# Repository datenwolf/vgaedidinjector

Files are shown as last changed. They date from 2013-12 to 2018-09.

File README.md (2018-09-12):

# VGA EDID Injector

Captures EDID information from a display and presents it to a computer. Useful in situations where the DDC lines are not connected (like the CCH).
* sources	https://github.com/datenwolf/vgaedidinjector
* project at C3VOC wiki	https://c3voc.de/wiki/hardware:vga_edid_injector

The VGA EDID Injector is a tool that aims to make the use of presentation infrastructure less painful. In many conference venues the presentation displays (video projectors aka "beamers") are connected using old fashioned analogue connections using high quality coax cable. While this method offers a very good image quality it suffers from the lack of a DDC channel for transmission of EDID data.

Modern operating systems however depend on the EDID information for mode setting. Even worse on some operating systems it is very hard or even impossible to override the settings obtained from the EDID data. Those operating systems also usually fall back to a set of safe display resolutions and timings if no EDID data could be retrieved via DDC. Unfortunately those safe timings usually don't match the physical resolution of the display device, resulting in bad looking scaling and/or worse distortion of the aspect ratio (e.g. fall back resolution 1024×768 (4:3 aspect), display device physical resolution 1280×720 (16:9) resulting in squashed image, i.e. pancake heads, and so on…).

The VGA EDID Injector provides relief for this kind of situation: It allows to take a snapshot of a display's EDID information and "carry" it to the computer in need.

## Hardware
The VGA EDID Injector has 3 connectors (see image):

* D-Sub 15 H (VGA) female, left side of the board – connect to display device
* D-Sub 15 H (VGA) male, right side of the board – connect to computer
* Micro-USB, lower side of the board – for providing auxiliary power (+5V); upcoming firmware revisions will provide a command line interface

## Usage
### Snapshoting Display EDID information

To snapshot the EDID connection you have to insert the injector in reverse direction. This typically requires you to use the VGA gender changer and the VGA cable.

* Connect the display to the left side, female VGA connector. 
* Plug the right side, male VGA connector into a computer

Using the display control tools refresh/identify connected displays. Repeat this until the attached display is recognized.
The VGA EDID Injector can now be spliced into the computer side of a video signal only (i.e. no DDC signals) connection.

### Replaying snapshoted EDID information
Insert the VGA EDID Injector into the video signal connection close to the computer.

**Important Notice:** There must be no DDC signals present on the display side of the connection. Otherwise the VGA EDID Injector will try to attempt to snapshot the information found there and, if successful, will overwrite the previously snapshoted EDID information.

In that case it is recommended to prepare a special VGA cable in which the signal carried over the pins 12 and 15 is severed (simply removing the pins from one of the connectors with some side cutters and/or pliers will do the trick).

### Micro-USB connector
An upcoming firmware release will provide a command line interface over USB CDC ACM serial device emulation. Until then the Micro-USB connector serves for supplying auxiliary power (+5V). Under normal circumstances the VGA connection will provide +5V, 50mA(max) over pin 9. However long cable lengths or a "weak" system's power supply (think laptops) may prevent the supply to meet the demands.

The circuitry of the VGA EDID Injector incorporates two rectifier diodes to prevent current to flow back into either the VGA port or the Micro-USB if both are connected at the same time, or should a computer get accidently connected on the display side. However those diodes create a 0.7V voltage drop.

Hence should the VGA EDID Injector seem to be nonoperational it is suggested to provide auxiliary power through the Micro-USB connector.

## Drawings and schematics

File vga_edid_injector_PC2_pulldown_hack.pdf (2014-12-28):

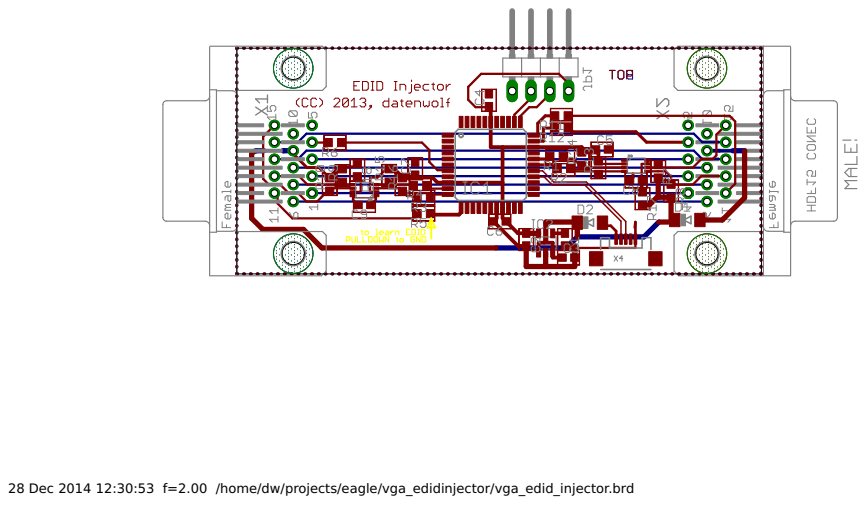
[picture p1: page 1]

28 Dec 2014 12:30:53 f=2.00 /home/dw/projects/eagle/vga_edidinjector/vga_edid_injector.brd

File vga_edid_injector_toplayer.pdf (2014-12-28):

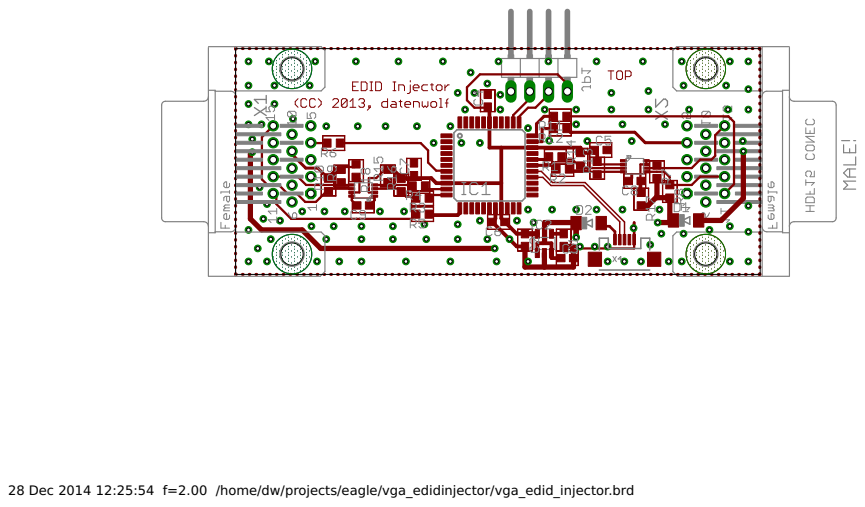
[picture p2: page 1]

28 Dec 2014 12:25:54 f=2.00 /home/dw/projects/eagle/vga_edidinjector/vga_edid_injector.brd

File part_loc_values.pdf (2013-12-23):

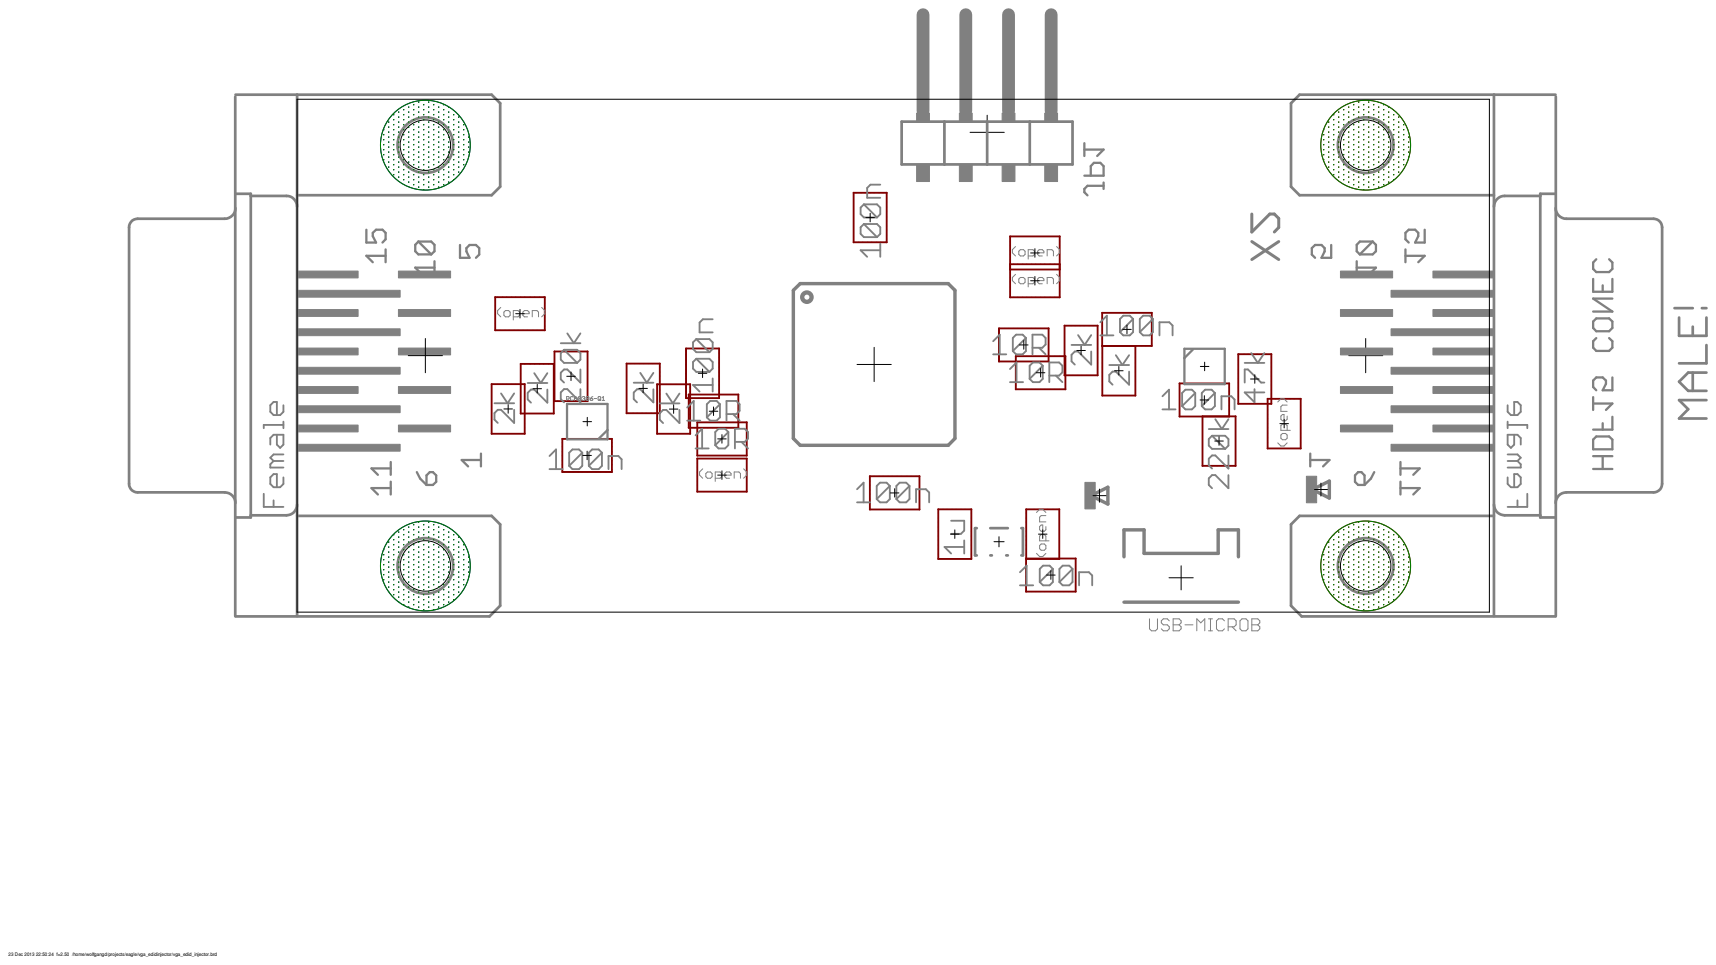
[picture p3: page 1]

23 Dec 2013 22:50:24 f=2.50 /home/wolfgangd/projects/eagle/vga_edidinjector/vga_edid_injector.brd

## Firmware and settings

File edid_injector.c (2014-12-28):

/* This file has been prepared for Doxygen automatic documentation generation.*/
/*! \file *********************************************************************
 *
 * \brief  EDID Injector firmware
 *
 * \author
 *      Wolfgang 'datenwolf' Draxinger
 *      Support email: projects+edid_injector@datenwolf.net
 *
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
 * 3. The name of ATMEL may not be used to endorse or promote products derived
 * from this software without specific prior written permission.
 *
 * THIS SOFTWARE IS PROVIDED BY ATMEL "AS IS" AND ANY EXPRESS OR IMPLIED
 * WARRANTIES, INCLUDING, BUT NOT LIMITED TO, THE IMPLIED WARRANTIES OF
 * MERCHANTABILITY AND FITNESS FOR A PARTICULAR PURPOSE ARE EXPRESSLY AND
 * SPECIFICALLY DISCLAIMED. IN NO EVENT SHALL ATMEL BE LIABLE FOR ANY DIRECT,
 * INDIRECT, INCIDENTAL, SPECIAL, EXEMPLARY, OR CONSEQUENTIAL DAMAGES
 * (INCLUDING, BUT NOT LIMITED TO, PROCUREMENT OF SUBSTITUTE GOODS OR SERVICES;
 * LOSS OF USE, DATA, OR PROFITS; OR BUSINESS INTERRUPTION) HOWEVER CAUSED AND
 * ON ANY THEORY OF LIABILITY, WHETHER IN CONTRACT, STRICT LIABILITY, OR TORT
 * (INCLUDING NEGLIGENCE OR OTHERWISE) ARISING IN ANY WAY OUT OF THE USE OF
 * THIS SOFTWARE, EVEN IF ADVISED OF THE POSSIBILITY OF SUCH DAMAGE.
 *****************************************************************************/
#include "avr_compiler.h"

#include <string.h>

#include "eeprom_driver.h"

#include "twi_master_driver.h"
#include "twi_slave_driver.h"

/*! BAUDRATE 100kHz and Baudrate Register Settings */
#define BAUDRATE	100000
#define TWI_BAUDSETTING TWI_BAUD(F_CPU, BAUDRATE)

#define EDID_SLAVE_ADDRESS 0x50

/* TWIC is on the display side */
TWI_t * const twiDisplay = &TWIC;
TWI_Master_t twimDisplay;    /*!< TWI master module. Used for talking with display */
/*! TWIC Master Interrupt vector. */
ISR(TWIC_TWIM_vect)
{
	TWI_MasterInterruptHandler(&twimDisplay);
}


/* TWIE is on the host side */
TWI_t * const twiHost = &TWIE;
TWI_Slave_t twisHost;      /*!< TWI slave module.  Used for talking with host */
/*! TWIC Slave Interrupt vector. */
ISR(TWIE_TWIS_vect)
{
	TWI_SlaveInterruptHandler(&twisHost);
}

#define EDID_BLOCK_LENGTH 128

static uint8_t edid_data[EDID_BLOCK_LENGTH];
static uint8_t edid_offset;
static uint8_t recvbuf[1];

void TWIC_SlaveProcessData(TWI_Slave_t * const twi)
{
	if( twi->bytesReceived ) {
		edid_offset = twi->recvData[0];
	}
	twi->sendData = edid_data + edid_offset;
	twi->bytesToSend = sizeof(edid_data) - edid_offset;
}

void edid_initHostTWI(void)
{
	/* Initialize TWI slave. */
	TWI_SlaveInitializeDriver(&twisHost,
		twiHost,
		TWIC_SlaveProcessData);

	TWI_SlaveInitializeModule(&twisHost,
		EDID_SLAVE_ADDRESS,
		TWI_SLAVE_INTLVL_HI_gc,
		recvbuf,
		sizeof(recvbuf) );
}

void edid_initDisplayTWI(void)
{
	/* Initialize TWI master. */
	twimDisplay.status = TWIM_STATUS_READY;
	TWI_MasterInit(&twimDisplay,
	               twiDisplay,
	               TWI_MASTER_INTLVL_LO_gc,
	               TWI_BAUDSETTING);

	/* Enable internal pull-up on PC0, PC1. */
	/* If you don't have external pullups enable this */
#if 0
	/* Configure several PINxCTRL registers at the same time */
	PORTCFG.MPCMASK = 0x03; 

	/* Enable pull-up to get a defined level on the switches */
	PORTC.PIN0CTRL = (PORTC.PIN0CTRL & ~PORT_OPC_gm) | PORT_OPC_PULLUP_gc;
#endif

}

uint8_t edid_checkData(uint8_t const *ediddata)
{
	uint8_t checksum = 0;
	for(uint8_t i = 0; i < EDID_BLOCK_LENGTH; i++) {
		checksum += ediddata[i];
	}
	if( 0 != checksum ) {
		return 1; /* checksum failed */
	}

	if( 0 != ediddata[0] ) {
		return 2; /* headerbyte[0] != 0 */
	}

	for(uint8_t i = 1; i < 7; i++) {
		if( 0xff != ediddata[i] ) {
			return 3; /* headerbyte[1..6] != 0xff */
		}
	}

	if( 0 != ediddata[7] ) {
		return 4; /* headerbyte[7] != 0 */
	}

	return 0; /* EDID data passed checks */
}

uint8_t edid_genChecksum(uint8_t *ediddata)
{
	uint8_t bytessum = 0;
	for(uint8_t i = 0; i < EDID_BLOCK_LENGTH-1; i++) {
		bytessum += ediddata[i];
	}

	return 0xff - bytessum + 1;
}

uint8_t edid_readFromDisplay(void)
{
	uint8_t const offset[1] = {0x00};
	uint8_t displayedid[EDID_BLOCK_LENGTH];
	memset(displayedid, 0, sizeof(displayedid));

	uint8_t error = 0;
	uint8_t retry = 20;
	while( retry-- ) {
		error = 0;

		TWI_MasterForceIdle(&twimDisplay);
		delay_ms(1);

		/* set EDID offset to 0 */
		if( !TWI_MasterWriteRead(&twimDisplay,
			EDID_SLAVE_ADDRESS,
			offset,
			sizeof(offset),
			displayedid,
			sizeof(displayedid) ) ) {
			PORTB.OUTCLR = (1<<3);
			PORTB.OUTSET = (1<<3);
		};

		while( !TWI_MasterReady(&twimDisplay) ) {
			delay_ms(1);
		}
		delay_ms(1);

		if( twimDisplay.result != TWIM_RESULT_OK ) {
			error = 1;
			continue;
		}

		if( edid_checkData(displayedid) ) {
			error = 2;
			continue;
		}

		break;
	}
	if( error ) {
		return error;
	}

	if( edid_checkData(displayedid) ) {
		return 3;
	}

	/* set EDID Extension Block count / flags to zero */
	displayedid[126] = 0;

	/* recalculate checksum */
	displayedid[127] = edid_genChecksum(displayedid);

	/* write EDID information to EEPROM */
	memcpy(edid_data, displayedid, EDID_BLOCK_LENGTH);

	return 0;
}

uint8_t edid_readFromEEPROM(void)
{
	uint8_t eepromedid[EDID_BLOCK_LENGTH];
	memset(eepromedid, 0, sizeof(EDID_BLOCK_LENGTH));

	EEPROM_WaitForNVM();
	EEPROM_FlushBuffer();
	EEPROM_DisableMapping();

	for(uint8_t i_page = 0;
	    i_page < EDID_BLOCK_LENGTH / EEPROM_PAGE_SIZE;
	    i_page++ ) {
		for(uint8_t i_b = 0; i_b < EEPROM_PAGE_SIZE; i_b++) {
			eepromedid[i_page * EEPROM_PAGE_SIZE + i_b] =
				EEPROM_ReadByte(i_page, i_b);
		}
	}

	if( edid_checkData(eepromedid) ) {
		/* EDID data read from EEPROM didn't pass sanity checks */
		// memset(edid_data, 0, EDID_BLOCK_LENGTH);
		return 1;
	}

	memcpy(edid_data, eepromedid, EDID_BLOCK_LENGTH);
	return 0;
}

void edid_writeToEEPROM(void)
{
	uint8_t pagebuf[EEPROM_PAGE_SIZE];

	EEPROM_WaitForNVM();
	EEPROM_FlushBuffer();
	EEPROM_DisableMapping();

	for(uint8_t i_page = 0;
	    i_page < EDID_BLOCK_LENGTH / EEPROM_PAGE_SIZE;
	    i_page++ ) {
		for(uint8_t i_b = 0; i_b < EEPROM_PAGE_SIZE; i_b++) {
			pagebuf[i_b] = EEPROM_ReadByte(i_page, i_b);
		}

		if( 0 == memcmp(pagebuf,
		                edid_data + i_page*EEPROM_PAGE_SIZE,
		                EEPROM_PAGE_SIZE )
		) {
			/* page unaltered skip writing it */
			continue;
		}

		memcpy(	pagebuf,
			edid_data + i_page*EEPROM_PAGE_SIZE,
			sizeof(pagebuf) );

		EEPROM_LoadPage( pagebuf );
		EEPROM_AtomicWritePage(i_page);
		EEPROM_WaitForNVM();
	}
}

int main(void)
{
	memset(edid_data, 0, sizeof(edid_data));

	edid_readFromEEPROM();

	edid_initHostTWI();
	edid_initDisplayTWI();

	/* Enable LO interrupt level. */
	PMIC.CTRL |=
		  PMIC_LOLVLEN_bm
		| PMIC_MEDLVLEN_bm
		| PMIC_HILVLEN_bm;
	
	PORTC_PIN2CTRL = PORT_OPC_WIREDANDPULL_gc;
	PORTC_DIRCLR   = _BV(2);
	PORTC_OUTSET   = _BV(2);

	sei();
	delay_ms(20); 

	/* EDID standard requires a host to wait for 20ms after switching +5V
	 * supply to display before performing the first readout attempt.
	 * Since uC supply == display +5V supply we're waiting 20ms here.
	 */
	for(;;) {
		/* Only read a new EDID setting if PC2 is pulled low */
		if( !(PORTC_IN & _BV(2)) ) {
			if( 0 == edid_readFromDisplay() ) {
				edid_writeToEEPROM();
				edid_readFromEEPROM();
			}
		}
		delay_ms(1000); 
	}

	return 0;
}

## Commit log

2013-11-19 PDI connector!
    [vga_edid_injector.brd, vga_edid_injector.sch]
2013-11-19 dimension and stitching vias
    [vga_edid_injector.brd]
2013-11-19 creator information silkscreen
    [vga_edid_injector.brd]
2013-12-21 values, schematic layout and value print placement
    [vga_edid_injector.brd, vga_edid_injector.sch]
2013-12-22 values value/name placement
    [vga_edid_injector.brd, vga_edid_injector.sch]
2013-12-22 Makefile separator errors fixed
    [edid_injector.c]
2013-12-23 reading EDID information from display and submission to host works
    [vga_edid_injector.brd, vga_edid_injector.sch]
2014-12-28 EDID readout only if PC2 pulled low
    [vga_edid_injector.brd, vga_edid_injector.sch]
2018-09-08 copy from https://web.archive.org/web/20140708233324/https://events.ccc.de/congress/2013/wiki/Projects:VGA_EDID_Injector
